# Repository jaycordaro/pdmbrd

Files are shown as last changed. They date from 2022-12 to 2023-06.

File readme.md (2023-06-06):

# PDMBRD 

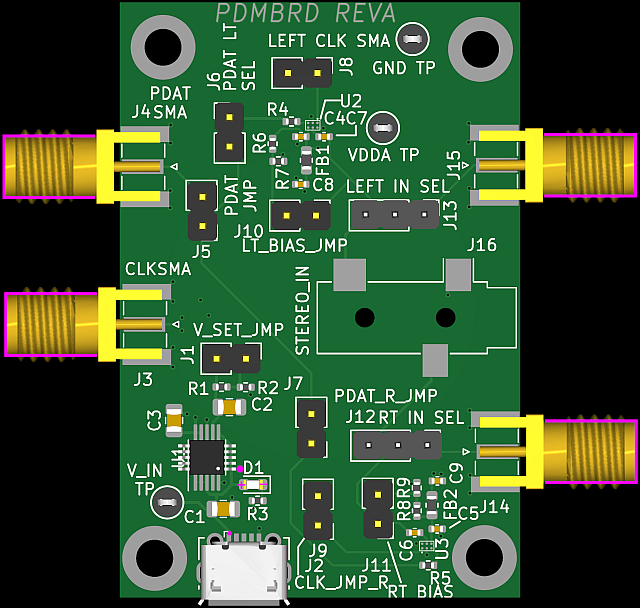
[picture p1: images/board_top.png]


## KiCAD 6.x board with two FAN3852 PDM analog to digital converters (ADCs).  

## Features

* Converts analog audio and ultrasound signals into digital Pulse Density Modulation (PDM) format
* Jumper selection for different options
* Accepts analog input signals from SMA connectors, jumper wire, or 3.5mm (1/8") stereo jack
* On-board low noise LT3042 voltage regulator (U1) powered from USB Micro provides 3.3V or 1.8V to the ADCs

* Board can be (mostly) assembled by JLCPCB (only U2 and UJ3 FAN3852 and J16 CUI SJ-3523-SMT audio jack need hand soldering)
* Much cheaper than OnSemi FAN3852 EVB 

## Equipment Required

* USB Micro cable for 5V power
* Analog source
* SMA and/or jumper wires to connect test equipment
* 3.5mm male stereo jack if using analog audio input
* PDMCLK source/PDMDAT Sink

## Operation

Set J1 to voltage of PDM input of the dut -- leave open for 3.3V and short for 1.8V operation.
Plug in J2 to a Micro USB jack to supply 5V to the board.
If the PDMCLK will be supplied via SMA, short jumpers J8/J9 for left and right channels respetively.  If feeding via jumper, insert female jumper wire to J8.1 and J9.1.
Short J6 and J7 to connect the left and right PDAT channels to J5.  If J5 will supply the PDAT output over SMA, short J5. If feeding via jumper, insert female jumper wire to J5.1.
Electret microphones require DC bias.  Short jumpers J10 and J11 to apply bias for the left and right channels, respectively.  

### Audio in over 3.5mm jack
Set J12 and J13 to 2-3.
insert a 3.5mm male jack into J16.  The figure below shows 1.8V operation with the jumpers configured for audio in over J16, 3.5mm jack.

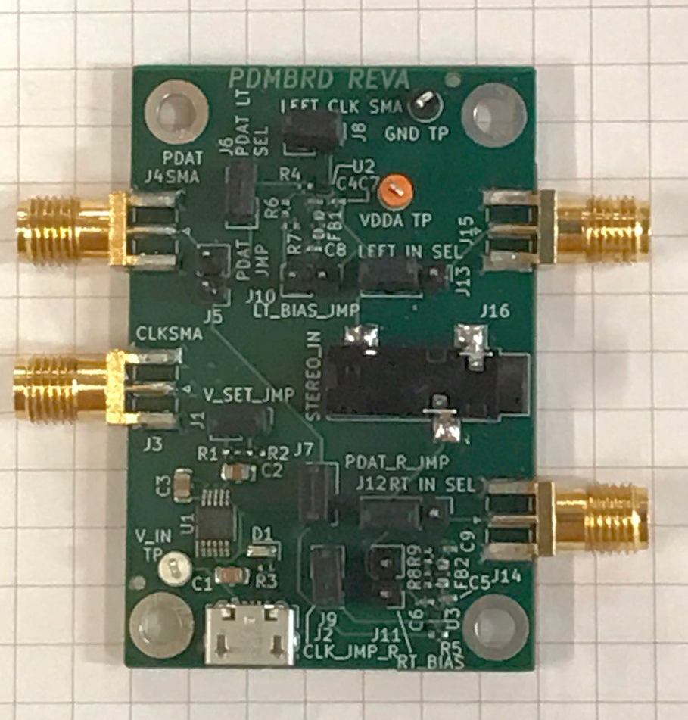
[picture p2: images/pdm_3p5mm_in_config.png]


## Audio in over SMA
Set j12 and J13 to 2-1 and connect SMA cables to signal generator(s)

## Fabrication

The board was fabricated at JLCPCB.  The directory .\jlcpcb\gerbers contains the zip of the gerbers in the format that JLCPCB requires.  Follow the directions that JLCPCB have on their website for fabricating boards with KiCAD 6.  [link](https://jlcpcb.com/help/article/16-How-to-generate-Gerber-and-Drill-files-in-KiCad-6).  
Layer stackup: 
* top layer: .gtl
* 2nd layer: .g2
* 3rd layer: .g3
* bottom layer: .gbl 

The JLCPCB BOM and XY files in .csv format are in .\jlcpcb\fabrication.  All devices were placed on the top layer for 'economic' JLCPCB assembly option.  The CUI SJ-3523-SMT audio jack and FAN3852UCX ADCs were not available for assembly at JLCPCB but are available from Mouser.  Note that FAN3852 is 0.4mm pitch.  If you are not experienced with soldering fine-pitch BGAs, ask someone to solder it for oyu.  
 
## License

Licensed under the TAPR Open Hardware License (www.tapr.org/OHL)

See the PDMBRD REV A User Guide and schematic for more information

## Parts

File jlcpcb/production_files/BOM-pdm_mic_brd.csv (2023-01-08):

Comment | Designator | Footprint | LCSC
0.1u | C4,R6,R7,R8,R9 | C_0402_1005Metric | C114762
1n | C6,C7 | C_0402_1005Metric | C126532
4.7u | C2,C3 | C_0805_2012Metric | C162427
FerriteBead | FB1,FB2 | L_0603_1608Metric | C19330
GND | TP2 | TestPoint_Keystone_5000-5004_Miniature | C238122
V_IN | TP1 | TestPoint_Keystone_5000-5004_Miniature | C238123
VDDA | TP3 | TestPoint_Keystone_5000-5004_Miniature | C238124
33 | R4,R5 | R_0402_1005Metric | C25105
15k | R1 | R_0402_1005Metric | C25756
18k | R2 | R_0402_1005Metric | C25762
RT_IN_SEL | J12,J13 | PinHeader_1x03_P2.54mm_Vertical | C2894926
1k | R3 | R_0402_1005Metric | C4109
ON | D1 | LED_0603_1608Metric | C434423
LT3042xMSE | U1 | MSOP-10-1EP_3x3mm_P0.5mm_EP1.68x1.88mm | C461518
USB_B_Micro | J2 | USB_Micro-B_Molex-105017-0001 | C505111
V_SET_JMP | J1,J10,J11,J5,J6,J7,J8,J9 | PinHeader_1x02_P2.54mm_Vertical | C5116481
RIGHT_SMA | J14,J15,J3,J4 | SMA_Samtec_SMA-J-P-X-ST-EM1_EdgeMount | C530661
4.7u | C1,C5,C8,C9 | C_0805_2012Metric | C60474
FAN3852 | U3 | FAN3852
MountingHole_Pad | H4 | MountingHole_3.2mm_M3_DIN965_Pad_TopBottom
MountingHole_Pad | H1 | MountingHole_3.2mm_M3_DIN965_Pad_TopBottom
AudioJack3 | J16 | Jack_3.5mm_CUI_SJ-3523-SMT_Horizontal
MountingHole_Pad | H3 | MountingHole_3.2mm_M3_DIN965_Pad_TopBottom
FAN3852 | U2 | FAN3852
MountingHole_Pad | H2 | MountingHole_3.2mm_M3_DIN965_Pad_TopBottom

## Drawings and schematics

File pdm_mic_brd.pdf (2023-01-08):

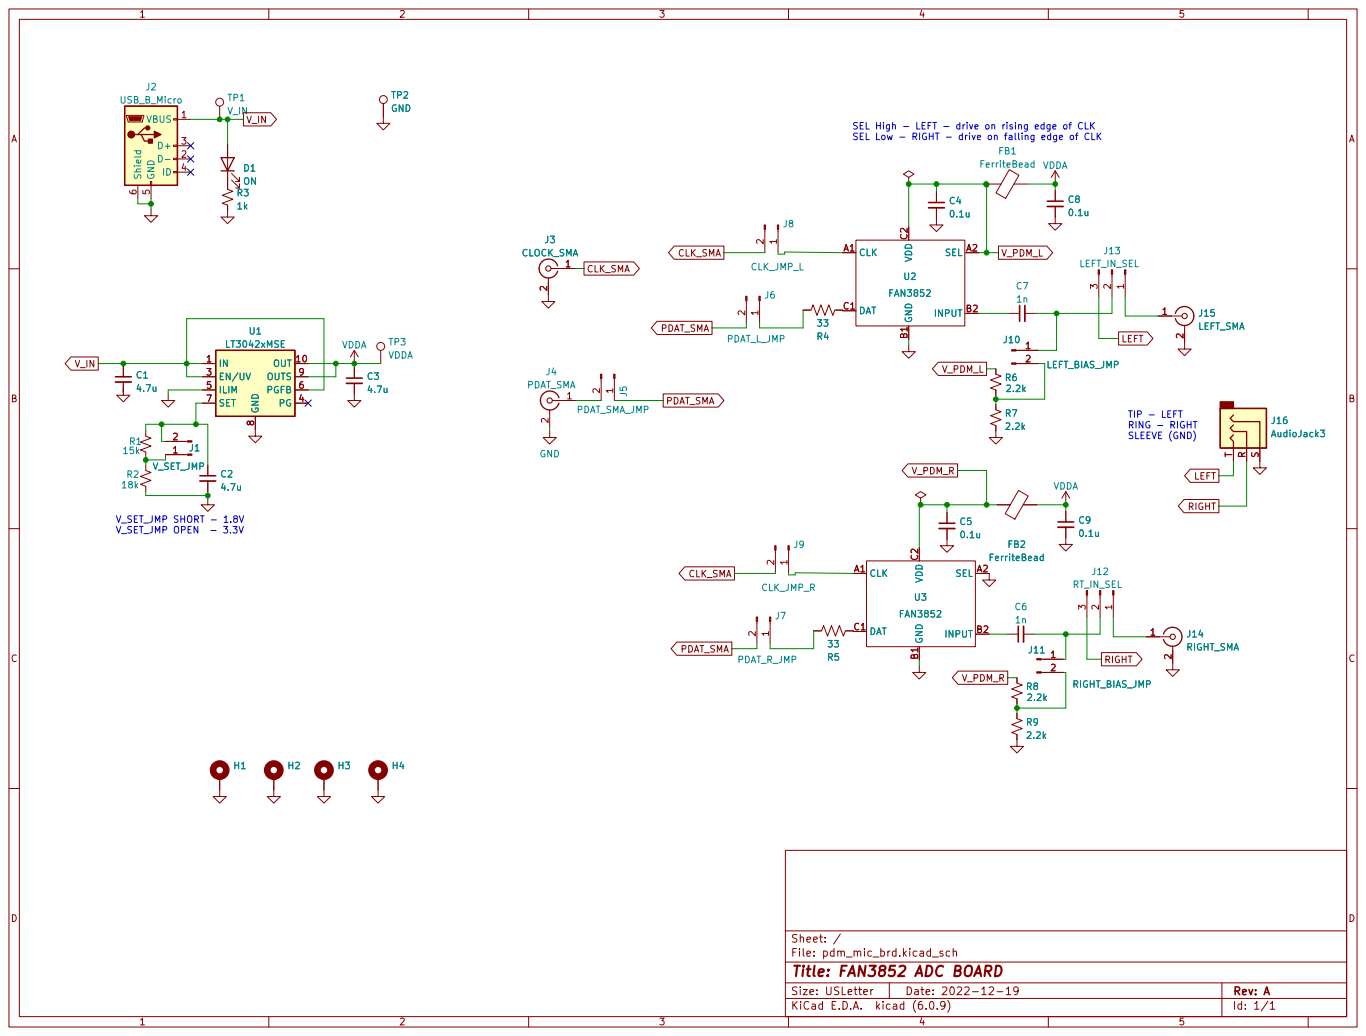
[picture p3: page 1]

SEL High - LEFT - drive on rising edge of CLK
SEL Low - RIGHT - drive on falling edge of CLK

TIP - LEFT RING - RIGHT SLEEVE (GND) C5
J16 AudioJack3 V_PDM_R

Id: 1/1 Title: FAN3852 ADC BOARD

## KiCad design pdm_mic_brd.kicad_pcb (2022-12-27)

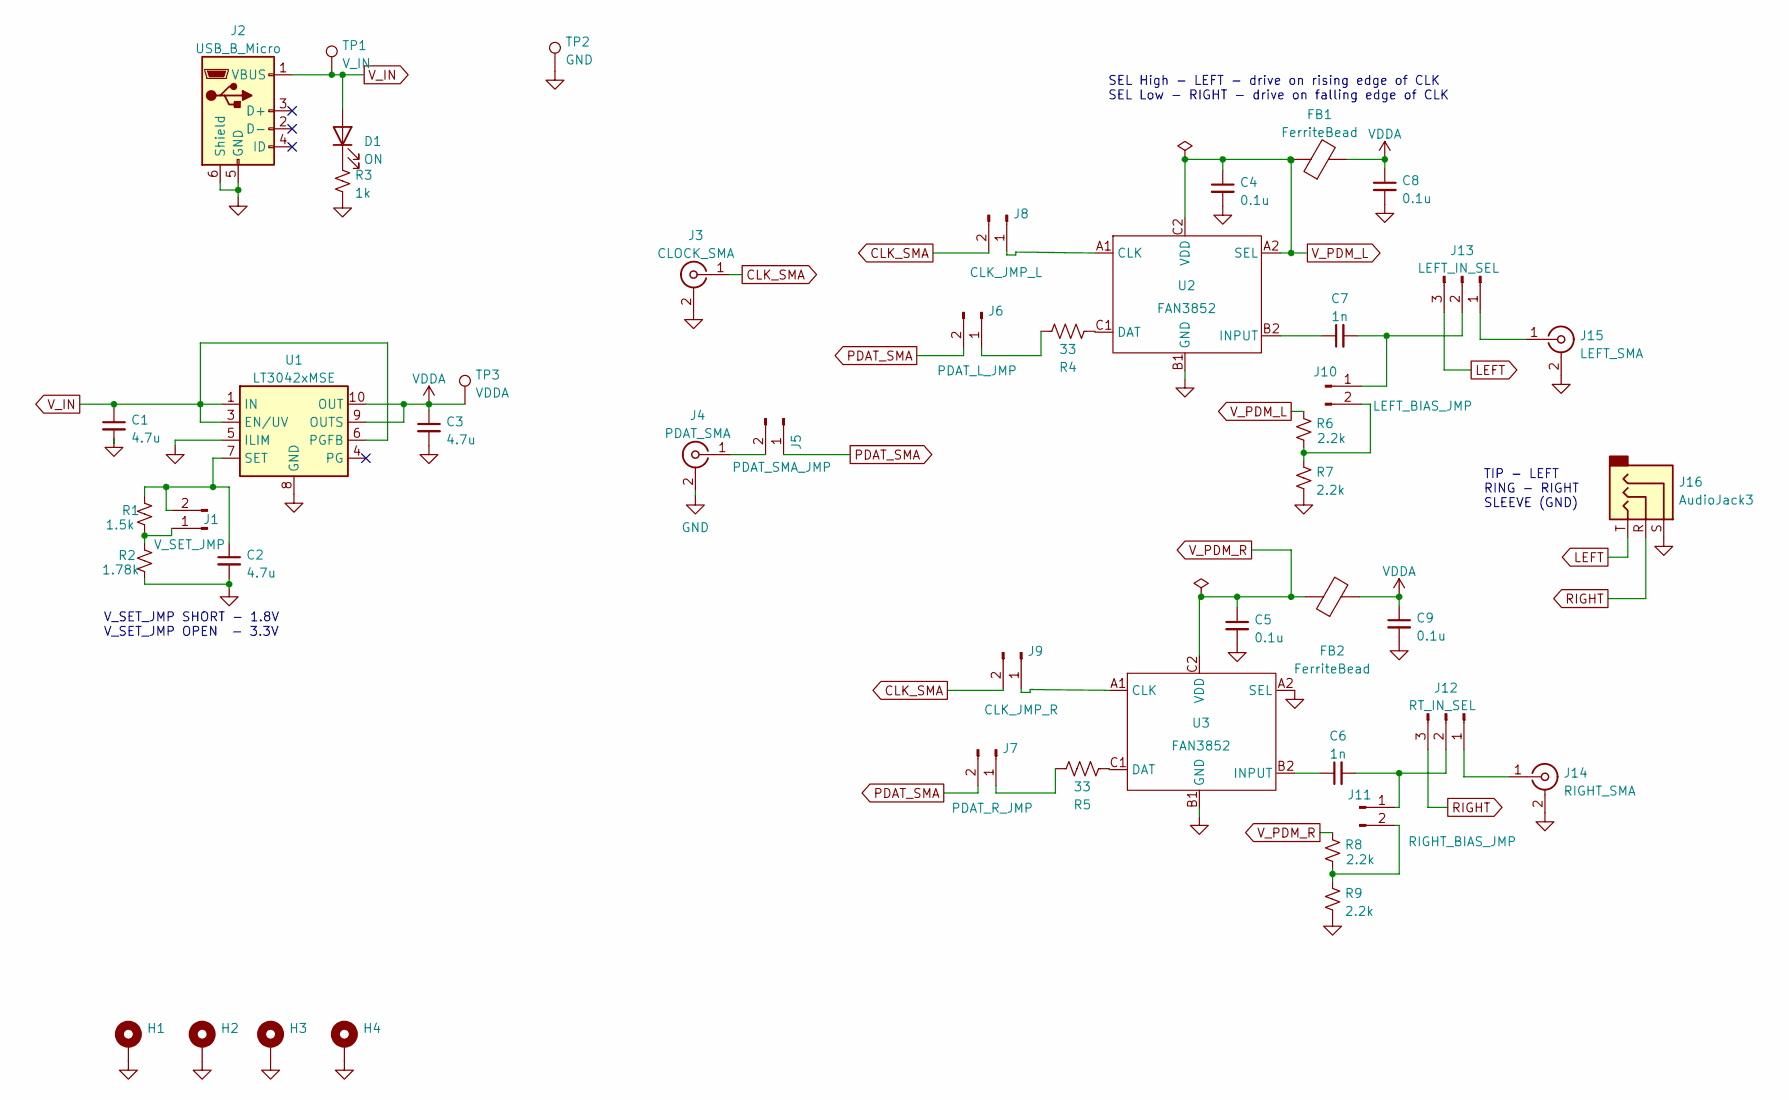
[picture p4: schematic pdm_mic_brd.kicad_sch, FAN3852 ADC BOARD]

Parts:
C1, C2, C3: 4.7u; C_0805_2012Metric; LCSC C408144
C4, C5, C8, C9: 0.1u; C_0402_1005Metric; LCSC C60474
C6, C7: 1n; C_0402_1005Metric; LCSC C126532
D1: ON; LED_0603_1608Metric; LCSC C434423
FB1, FB2: FerriteBead; L_0603_1608Metric; LCSC C19330
H1, H2, H3, H4: MountingHole_Pad; MountingHole_3.2mm_M3_DIN965_Pad_TopBottom
J1: V_SET_JMP; PinHeader_1x02_P2.54mm_Vertical; LCSC C5116481
J2: USB_B_Micro; USB_Micro-B_Molex-105017-0001; LCSC C505111
J3: CLOCK_SMA; SMA_Samtec_SMA-J-P-X-ST-EM1_EdgeMount; LCSC C530661
J4: PDAT_SMA; SMA_Samtec_SMA-J-P-X-ST-EM1_EdgeMount; LCSC C530661
J5: PDAT_SMA_JMP; PinHeader_1x02_P2.54mm_Vertical; LCSC C5116481
J6: PDAT_L_JMP; PinHeader_1x02_P2.54mm_Vertical; LCSC C5116481
J7: PDAT_R_JMP; PinHeader_1x02_P2.54mm_Vertical; LCSC C5116481
J8: CLK_JMP_L; PinHeader_1x02_P2.54mm_Vertical; LCSC C5116481
J9: CLK_JMP_R; PinHeader_1x02_P2.54mm_Vertical; LCSC C5116481
J10: LEFT_BIAS_JMP; PinHeader_1x02_P2.54mm_Vertical; LCSC C5116481
J11: RIGHT_BIAS_JMP; PinHeader_1x02_P2.54mm_Vertical; LCSC C5116481
J12: RT_IN_SEL; PinHeader_1x03_P2.54mm_Vertical; LCSC C2894926
J13: LEFT_IN_SEL; PinHeader_1x03_P2.54mm_Vertical; LCSC C2894926
J14: RIGHT_SMA; SMA_Samtec_SMA-J-P-X-ST-EM1_EdgeMount; LCSC C530661
J15: LEFT_SMA; SMA_Samtec_SMA-J-P-X-ST-EM1_EdgeMount; LCSC C530661
J16: AudioJack3; Jack_3.5mm_CUI_SJ-3523-SMT_Horizontal; MOUSER 490-SJ-3523-SMT-TR
R1: 1.5k; R_0402_1005Metric; LCSC C226693
R2: 1.78k; R_0402_1005Metric; JLC C226695
R3: 1k; R_0402_1005Metric; LCSC C4109
R4, R5: 33; R_0402_1005Metric; LCSC C25105
R6, R7, R8, R9: 2.2k; R_0402_1005Metric
TP1: V_IN; TestPoint_Keystone_5000-5004_Miniature; LCSC C238123
TP2: GND; TestPoint_Keystone_5000-5004_Miniature; LCSC C238122
TP3: VDDA; TestPoint_Keystone_5000-5004_Miniature; LCSC C238124
U1: LT3042xMSE; MSOP-10-1EP_3x3mm_P0.5mm_EP1.68x1.88mm; LCSC C461518
U2, U3: FAN3852; MOUSER 863-FAN3852UC16X

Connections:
CLK_SMA: J3.1 (In), J8.2, J9.2
GND: C1.2, C2.2, C3.2, C4.2, C5.2, C8.2, C9.2, H1.1, H2.1, H3.1, H4.1, J2.5 (GND), J2.6 (Shield), J3.2 (Ext), J4.2 (Ext), J14.2 (Ext), J15.2 (Ext), J16.S, R2.2, R3.2, R7.2, R9.2, TP2.1, U1.5 (ILIM), U1.8 (GND), U1.11 (GND), U2.B1 (GND), U3.A2 (SEL), U3.B1 (GND)
LEFT: J13.3, J16.T
unnamed: C2.1, J1.2, R1.1, U1.7 (SET)
unnamed: C6.1, U3.B2 (INPUT)
unnamed: C6.2, J11.1, J12.2
unnamed: C7.1, U2.B2 (INPUT)
unnamed: C7.2, J10.1, J13.2
unnamed: D1.1 (K), R3.1
unnamed: J1.1, R1.2, R2.1
unnamed: J4.1 (In), J5.2
unnamed: J6.1, R4.2
unnamed: J7.1, R5.2
unnamed: J8.1, U2.A1 (CLK)
unnamed: J9.1, U3.A1 (CLK)
unnamed: J10.2, R6.2, R7.1
unnamed: J11.2, R8.2, R9.1
unnamed: J12.1, J14.1 (In)
unnamed: J13.1, J15.1 (In)
unnamed: R4.1, U2.C1 (DAT)
unnamed: R5.1, U3.C1 (DAT)
PDAT_SMA: J5.1, J6.2, J7.2
RIGHT: J12.3, J16.R
VDDA: C3.1, C8.1, C9.1, FB1.2, FB2.2, TP3.1, U1.9 (OUTS), U1.10 (OUT)
V_IN: C1.1, D1.2 (A), J2.1 (VBUS), TP1.1, U1.1 (IN), U1.2 (IN), U1.3 (EN/UV), U1.6 (PGFB)
V_PDM_L: C4.1, FB1.1, R6.1, U2.A2 (SEL), U2.C2 (VDD)
V_PDM_R: C5.1, FB2.1, R8.1, U3.C2 (VDD)

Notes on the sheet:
SEL High - LEFT - drive on rising edge of CLK SEL Low - RIGHT - drive on falling edge of CLK
TIP - LEFT RING - RIGHT SLEEVE (GND)
V_SET_JMP SHORT - 1.8V V_SET_JMP OPEN - 3.3V

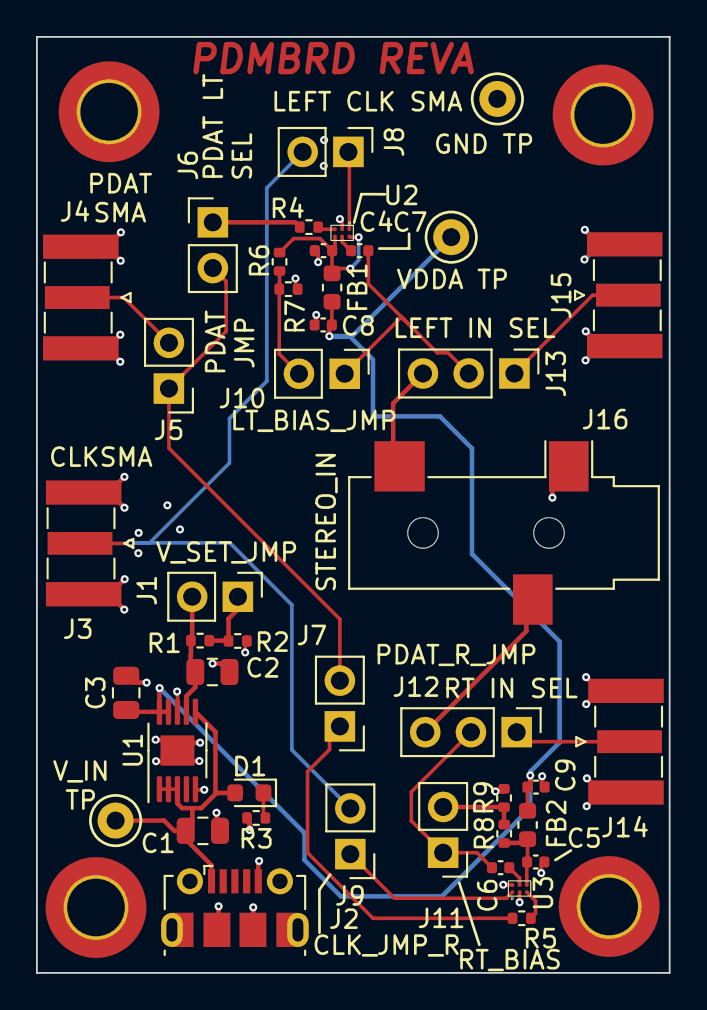
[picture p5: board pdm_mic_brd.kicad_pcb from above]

Board: 4 copper layers, 35.2 x 52.0 mm, 47 parts (0 on the bottom side), 27 nets.

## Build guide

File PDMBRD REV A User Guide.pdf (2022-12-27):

# PDMBRD REV A User Guide

## Jay Cordaro

## December 24, 2022

Features

Equipment Required

Description

Test Point Listing

Jumper Listing

IC Listing

Configuration

Operation

Schematic

Fabrication

Bill of Materials

Revision History

# Features

- Converts analog audio and ultrasound signals to Pulse Density Modulation (PDM) format
- Jumper selection for options
- Accepts analog input signals via 3.5mm stereo jack, SMAs, or jumper wire
- Powered from USB
- On-board voltage regulator

# Equipment Required

- USB Micro cable for 5V power
- Analog source
- SMA and/or jumper wires to connect test equipment
- 3.5mm male stereo jack if using audio input
- PDMCLK source/PDMDAT Sink

# Description

The BDMBRD REV A board converts analog single channel or stereo audio signals into digital Pulse Density Modulation (PDM) format data using two OnSemi FAN3852 Analog to Digtal Converters (ADCs). The board can be used to characterize and test audio front ends with PDM input for ASICs, FPGAs, and microcontrollers in a controlled manner, to test the effect of clock jitter on PDM audio quality, and as a non-acoustic (quiet) production testing method of machine learning ASIC models which require PDM audio input data. The board is powered by USB Micro and features an on-board ultra low noise regulator to supply power to the ADCs.

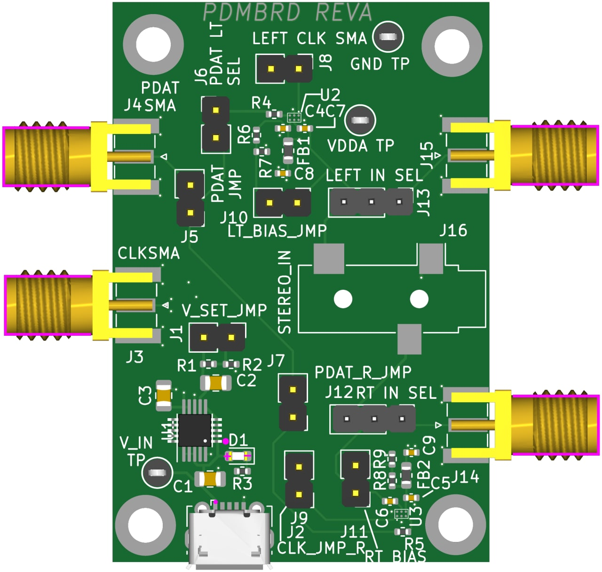
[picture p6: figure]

Figure 1
PCB Top Drawing

Refer to Figure 1, above for the PCB Top drawing of the board.

# Test Point Listing

Test Point | Name | Description
TP1 | V_IN | Test Point for 5V In
TP2 | GND | Ground
TP3 | VDDA | Test point for 3.3V or 1.8V regulated output

# Jumper Listing

Jumper | Name | Description
J1 | V_SET_JUMP | Open - set VDDA to 3.3V Closed - set VDDA to 1.8V
J2 | USB_B_MICRO | 5V power in via USB
J3 | CLK_SMA | SMA jack for PDMCLK
J4 | PDAT_SMA | SMA jack for PDAT
J5 | PDAT_SMA_JMP | Open - J5.1 supplies PDAT via jumper Closed - PDAT supplied to J4
J6 | PDAT_L_JMP | Open - Left channel does not drive PDAT Closed - Left channel drives PDAT
J7 | PDAT_R_JMP | Open - Right channel does not drive PDAT Closed - Right channel drives PDAT
J8 | CLK_JMP_L | Open - Left channel PCLK not driven by CLK_SMA (J3). Use if supplying left channel CLK via jumper wire Closed - Left Channel PCLK driven by CLK_SMA
J9 | CLK_JMP_R | Open - Right channel PCLK not driven by CLK_SMA (J3). Use if supplying right ch CLK via jumper wire Closed - Right Channel PCLK driven by CLK_SMA
J10 | LEFT_BIAS_JMP | Open - left ADC input not biased. Closed - add bias to ADC See FAN3852 DS
J11 | RIGHT_BIAS_JMP | Open - right ADC input not biased.

Jumper | Name | Description
| | Closed - add bias to ADC See FAN3852 DS
J12 | RT_IN_SEL | J12.2-1 - SMA (J14) ADC input for Right channel J12.2-3 - Audio Jack input for Right channel
J13 | LEFT_IN_SEL | J13.2-1 -SMA (J15) ADC input for Left channel J13.2-3 - Audio Jack input for Left channel
J14 | RIGHT_SMA | Input for right channel if J12 set to 2-1 and not using J16 audio jack. Useful for connecting signal generators to ADC input.
J15 | LEFT_SMA | Input for left channel if J13 set to 2-1 and not using J16 audio jack. Useful for connecting signal generators to ADC input
J16 | AudioJack3 | 3.5mm Audio Jack. J12 and J13 must be set to 2-3 Tip - Left Ring - Right Sleeve -GND

# Configuration

Configure the audio input source using jumpers J13 for the left channel and J12 for right channel. J13.2-1 selects J15 SMA input for the left channel and J12.2-1 selects the right channel as SMA input. J13.2-3 selects the left and J12.2-3 selects the right channels for the 3.5mm (⅛”) stereo jack.

Bias to the ADC inputs, for example when connecting ECM microphones to the left and right channels, can be enabled by shorting J10 for the left microphone J11 for the right microphone. If bias is not required, leave these jumpers unpopulated.

# Operation

FAN3852 datasheet (https://www.onsemi.com/download/data-sheet/pdf/fan3852-d.pdf) figures 5 and 6 show best SNR at -6dB FS which corresponds to 275mV peak to peak (not RMS) with SNR and THD dropping until 0dB FS which corresponds to 550mV pk-pk.

The FAN3852 datasheet lists FCLK min as 1.0MHz however, the ADCs have been tested to work down to at least 768kHz.

# Schematic

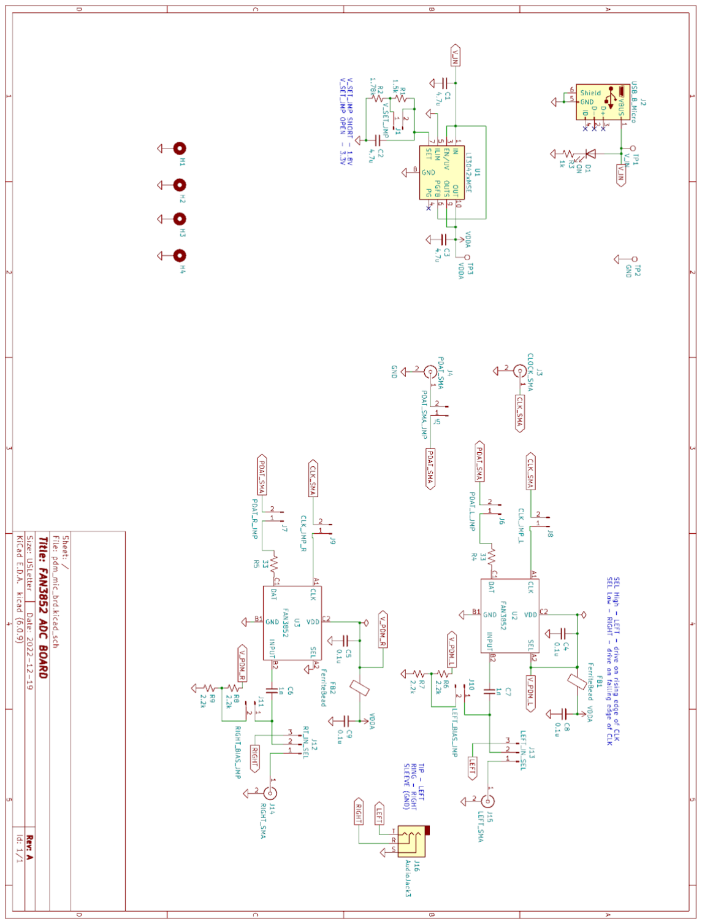
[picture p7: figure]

# Fabrication

KiCAD files are on the github repo.

To fabricate the board, upload the Gerber .zip file, BOM-pdm_mic_brd.csv BOM and XY file CPL-pdm_mic_brd.csv to JLCPCB

# Bill of Materials

Designator | Value | Type | PKG | Vendor | Vendor Part | LCSC | Mouser
C1,C2,C3 | 4.7uF | Capacitor, X7R | 0805 | Murata | GRM21BR71E475KA73L | C162427
C4,C5,C8,C9 | 0.1uF | Capacitor, X7R | 0402 | YAGEO | CC0402KRX7R7BB104 | C60474
C6,C7 | 1nF | Capacitor, X7R | 0402 | Murata | GCM155R71H102KA37D | C126532
D1 | ON LED | Grn/Yel LED | | Yongyu Photoelectric | SZYY0603YG | C434423
FB1,FB2 | FerriteBead | Ferrite Bead | 0603 | Murata | BLM18AG601SN1D | C19330
J1,J10,J11,J5 ,J6,J7,J8,J9 | 2 Pin Jumper | 2x2.54mm | | ZHOURI | 2.54-1*2 | C5116481
J12,J13 | 3 Pin Jumper | 3x2.54mm | | HCTL | PZ254-1-03-Z-8.5 | C2894926
J14,J15,J3,J4 | SMA | Coax Conn | | Shenzhen Kinghelm Elec | KH-SMA-KE8-G | C530661
J16 | 3.5mm Jack | Audio Jack | | CUI | SJ-3523-SMT-TR | | 490-SJ-3523-SMT-TR
J2 | USB_B_Micro | USB Micro | | MOLEX | 1050171001 | C505111
R1 | 1.5kΩ | Resistor | 0402 | YAGEO | AC0402DR-071K5L | C226693
R2 | 1.78kΩ | Resistor | 0402 | YAGEO | AC0402DR-071K78L | C226695
R3 | 1kΩ | Resistor | 0402 | UNI-ROYAL | 0402WGF2001TCE | C4109
R4,R5 | 33Ω | Resistor | 0402 | UNI-ROYAL | 0402WGF330JTCE | C25105
R6,R7,R8,R9 | 2.2kΩ | Resistor | 0402 | YAGEO | RC0402FR-072K2L | C114762
TP1 | V_IN | Test Point | | Keystone | 5002 | C238123
TP2 | GND | Test Point | | Keystone | 5001 | C238122
TP3 | VDDA | Test Point | | Keystone | 5003 | C238124
U1 | LT3042xMSE | LDO | MSOP-10 | ADI | LT3042EMSE#TRPBF | C461518
U2,U3 | | PDM ADC | | OnSemi | FAN3852UC16X | | 863-FAN3852UC16X

# Revision History

Date | Revision | Description
12/24/2022 | 0.1 | Initial Version

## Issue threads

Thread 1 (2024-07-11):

Minimal version ?

sekisushai, 2024-07-11:
Hello
Thank you for this great project.
I was wondering if you have a minimal version with 3.5mm jack input only and dupont cable socket output on a very small board to have an embedded version.
Thank you

jaycordaro, 2024-07-17:
I do not and do not plan to.  I provided the schematic in KiCAD format licensed in OHL.  Feel free to make your own design based on this one.

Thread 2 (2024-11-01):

Ultrasound applications

pauljunsukhan, 2024-11-01:
Awesome board! Thanks for making this public. You mentioned ultrasound applications - could you detail more? The FAN3852 has a 20kHz input bw

jaycordaro, 2025-02-11:
hi.  So the FAN3852 has a specification of 20kHz input BW but there is no anti-alias filter.  So, run f_clk as high as possible.  It is specified up to 4MHz in the datasheet but I have gone as high as 4.8MHz f_clk.  In my testing you can get to between 60kHz and 100kHz.  Note that this is operating it outside of the specification.

Closed 2025-02-11.

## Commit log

2023-01-08 fix R1 and R2 values
    [BOM-pdm_mic_brd.csv]
2023-01-08 fix R1, R2 values
    [CPL-pdm_mic_brd.csv]
2023-01-08 fix R1, R2 values
    [pdm_mic_brd.kicad_sch]
